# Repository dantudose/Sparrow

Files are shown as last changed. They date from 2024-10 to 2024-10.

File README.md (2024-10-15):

# Sparrow

## Arduino-compatible IoT sensor node made from two boards: the Node and the Nest - used for programming and debugging.

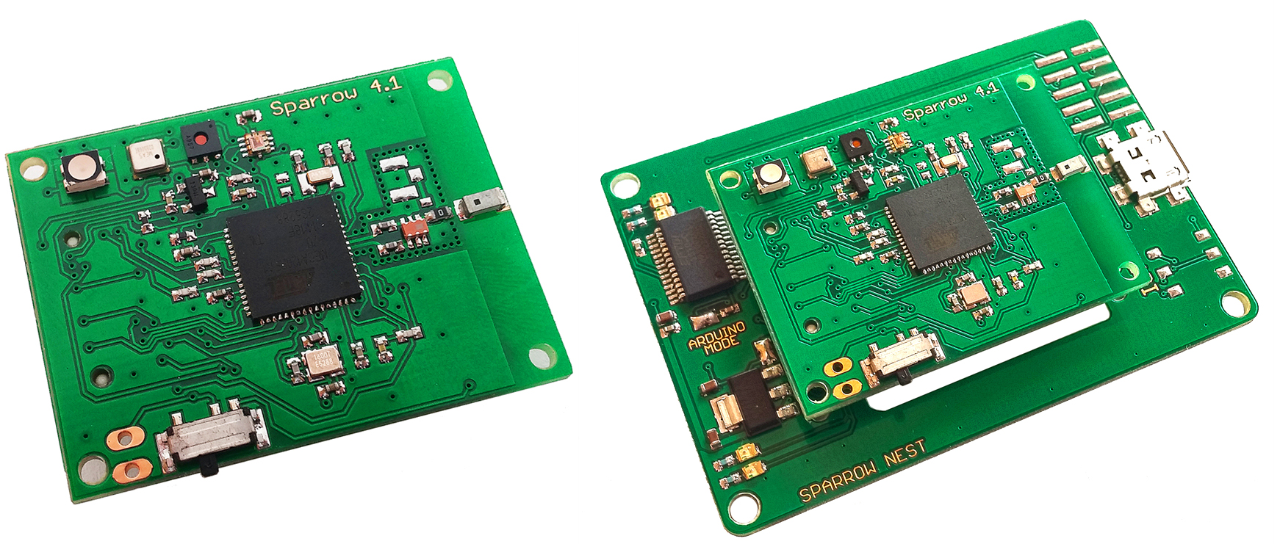
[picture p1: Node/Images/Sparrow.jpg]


Features include:

* Atmega128RFA1 8-bit AVR low-power microcontroller
* Integrated 2.4GHz radio transceiver
* Precision temperature & humidity sensor
* Barometer/altimeter
* Light sensor (visible, IR and UV spectrum, luxmeter and UV radiation index)
* High capacity CR2450 battery holder
* Fully-compatible with Arduino, with dedicated libraries for easy programming of the sensors and radio.

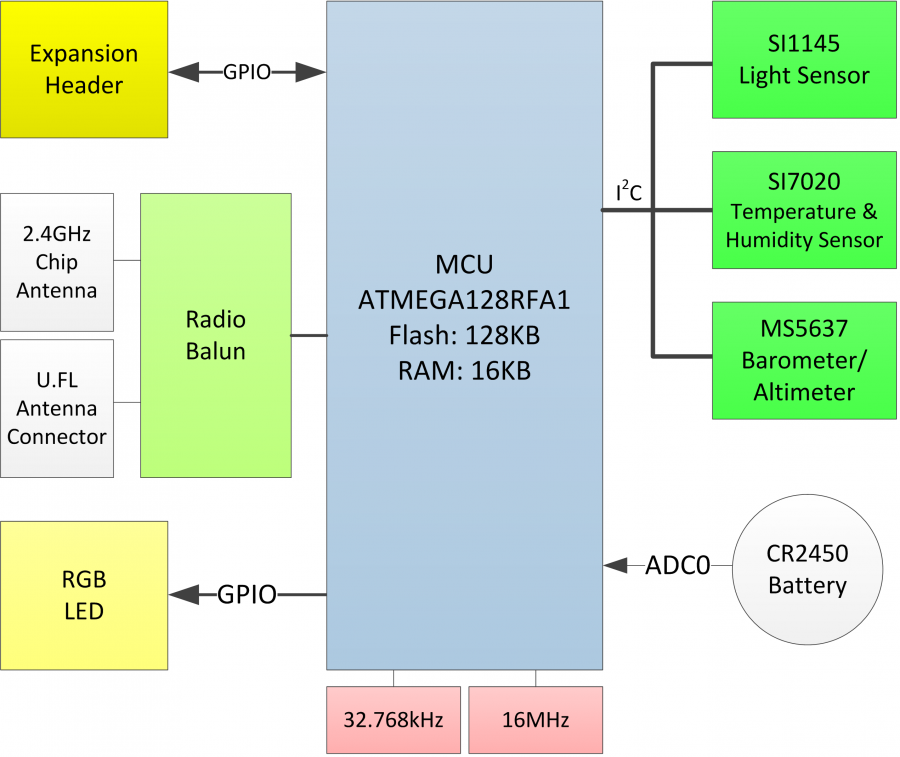
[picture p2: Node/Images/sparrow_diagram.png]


## Repository Contents

* **/Hardware** - Eagle design files (.brd, .sch)
* **/Images** - Board images
* **/bin** - Binaries (board bootloader)

## Programming

### Installing Arduino Libraries and Boad Configs

1. Open the Arduino IDE
2. Go to File → Preferences
3. In the Additional Boards Manager URLs textbox add the following link: http://clkdiv8.com/download/package_clkdiv8pre_index.json
4. Close the window by pressing OK
5. Go to Tools → Board → Boards Manager
6. Search “sparrow”
7. Hit Install
8. You're done!

### Tutorials

Most tutorials for using the on-board sensors or radio are available <a href="https://clkdiv8.com/wiki/doku.php/tutorials">here</a>.

### Bootloader
The board comes pre-loaded with a bootloader. Should you need to re-write it, connect an AVR-ISP or JTAG to the corresponding port and burn the <a href="https://github.com/dantudose/Sparrow/blob/main/Node/bin/">bootloader</a> .hex file with _atmega128rfa1_ as a target and the following fuse settings:

<table>
<thead>
  <tr>
    <th>Fuse</th>
    <th>Value</th>
  </tr>
</thead>
<tbody>
  <tr>
    <td>HIGH</td>
    <td>0xD0</td>
  </tr>
  <tr>
    <td>LOW</td>
    <td>0xF7</td>
  </tr>
  <tr>
    <td>EXT</td>
    <td>0XFE</td>
  </tr>
</tbody>
</table>

## Pinout and Sensor Addresses

<table><thead>
  <tr>
    <th></th>
    <th>GPIO Pin</th>
    <th>Arduino Pin</th>
    <th></th>
    <th>Sensor</th>
    <th>I2C Address</th>
  </tr></thead>
<tbody>
  <tr>
    <td>LED R</td>
    <td>PB4</td>
    <td>8</td>
    <td></td>
    <td>Si1145</td>
    <td>0x60</td>
  </tr>
  <tr>
    <td>LED G</td>
    <td>PB5</td>
    <td>11</td>
    <td></td>
    <td>Si7020</td>
    <td>0x40</td>
  </tr>
  <tr>
    <td>LED B</td>
    <td>PB6</td>
    <td>10</td>
    <td></td>
    <td>MS5637</td>
    <td>0x76</td>
  </tr>
  <tr>
    <td>Sensor <br>Enable <br> (Active LOW)</td>
    <td>PE7</td>
    <td>19</td>
    <td></td>
    <td></td>
    <td></td>
  </tr>
  <tr>
    <td>Battery<br>Level</td>
    <td>PF0</td>
    <td>A0</td>
    <td></td>
    <td></td>
    <td></td>
  </tr>
</tbody>
</table>

## License Information

This product is _**open source**_! 

Please review the LICENSE file for license information.

Distributed as-is; no warranty is given.

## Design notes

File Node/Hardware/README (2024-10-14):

Eagle (Fusion360) files and schematic in pdf format.

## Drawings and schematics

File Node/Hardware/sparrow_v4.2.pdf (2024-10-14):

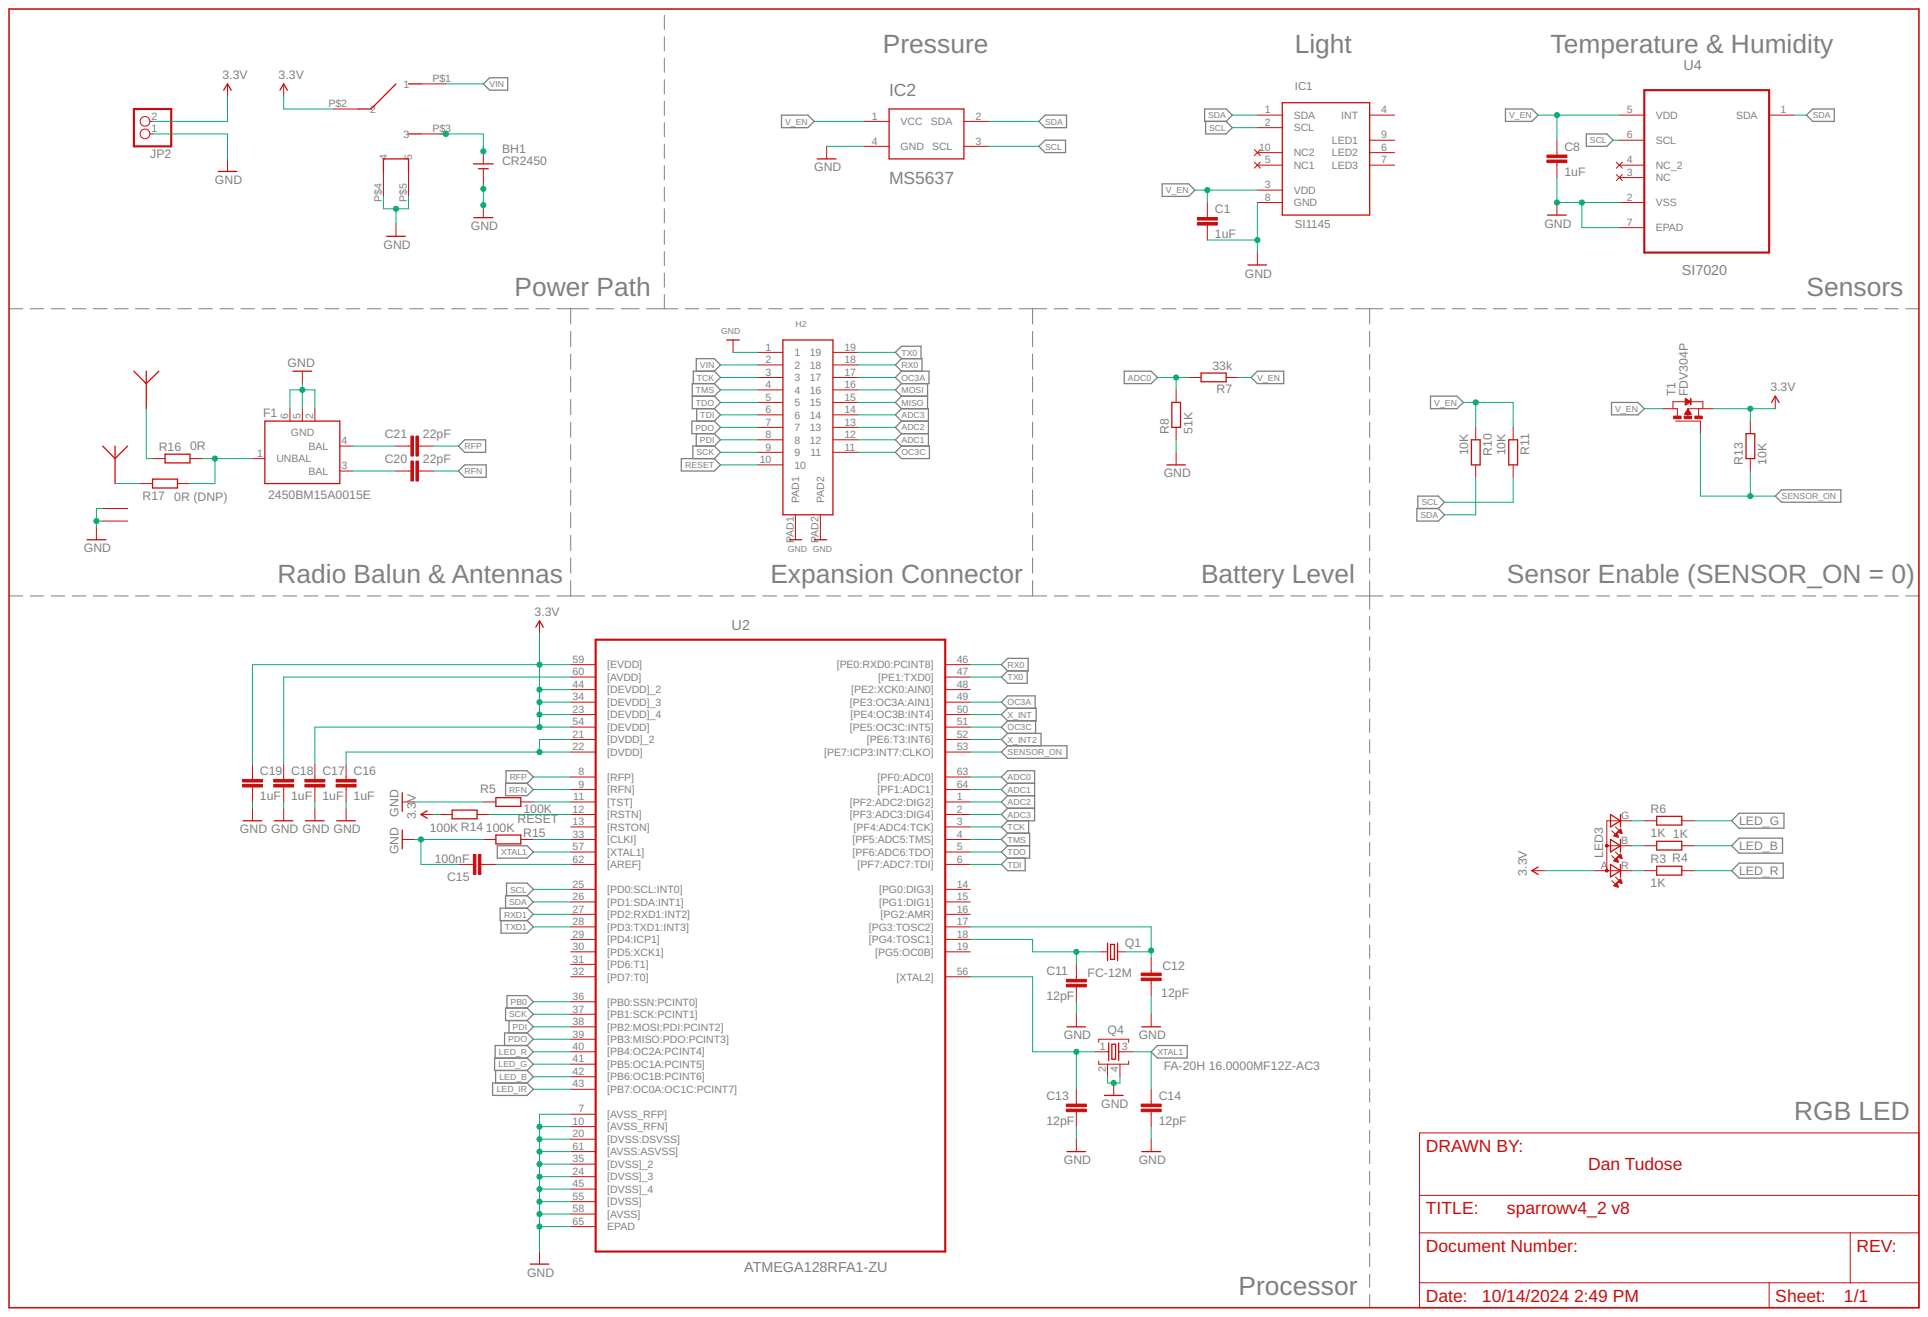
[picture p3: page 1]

Date: Sheet: | REV: TITLE: Document Number:

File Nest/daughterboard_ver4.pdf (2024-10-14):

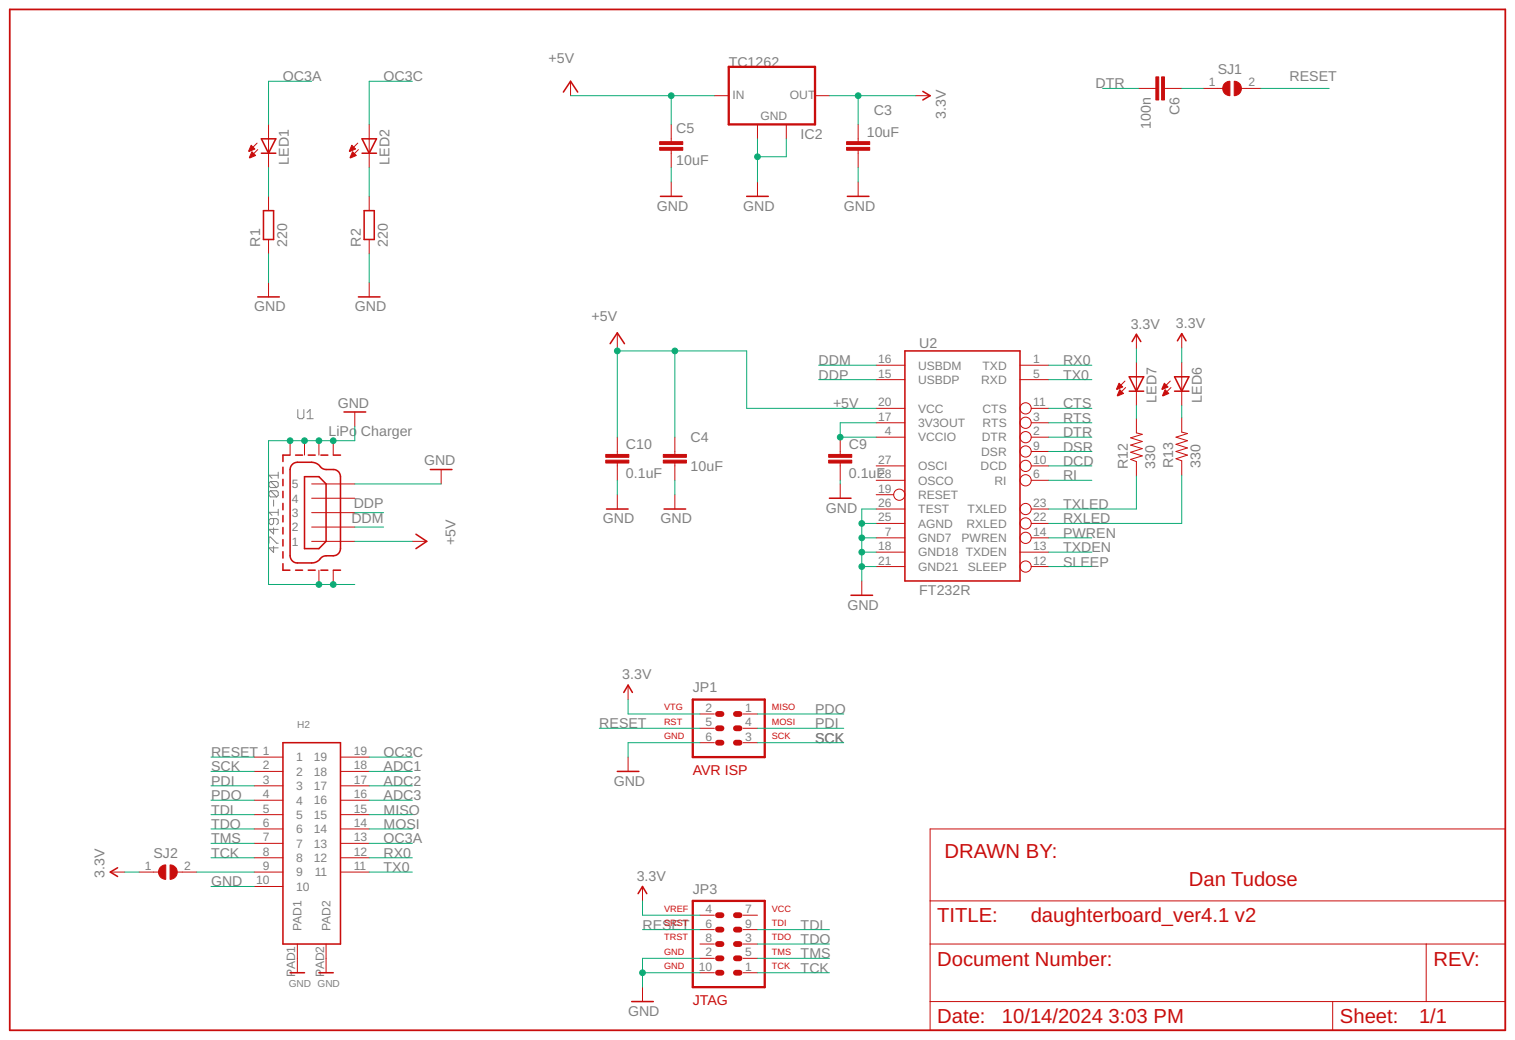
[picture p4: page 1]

Document Number: | REV:

Date: | Sheet:

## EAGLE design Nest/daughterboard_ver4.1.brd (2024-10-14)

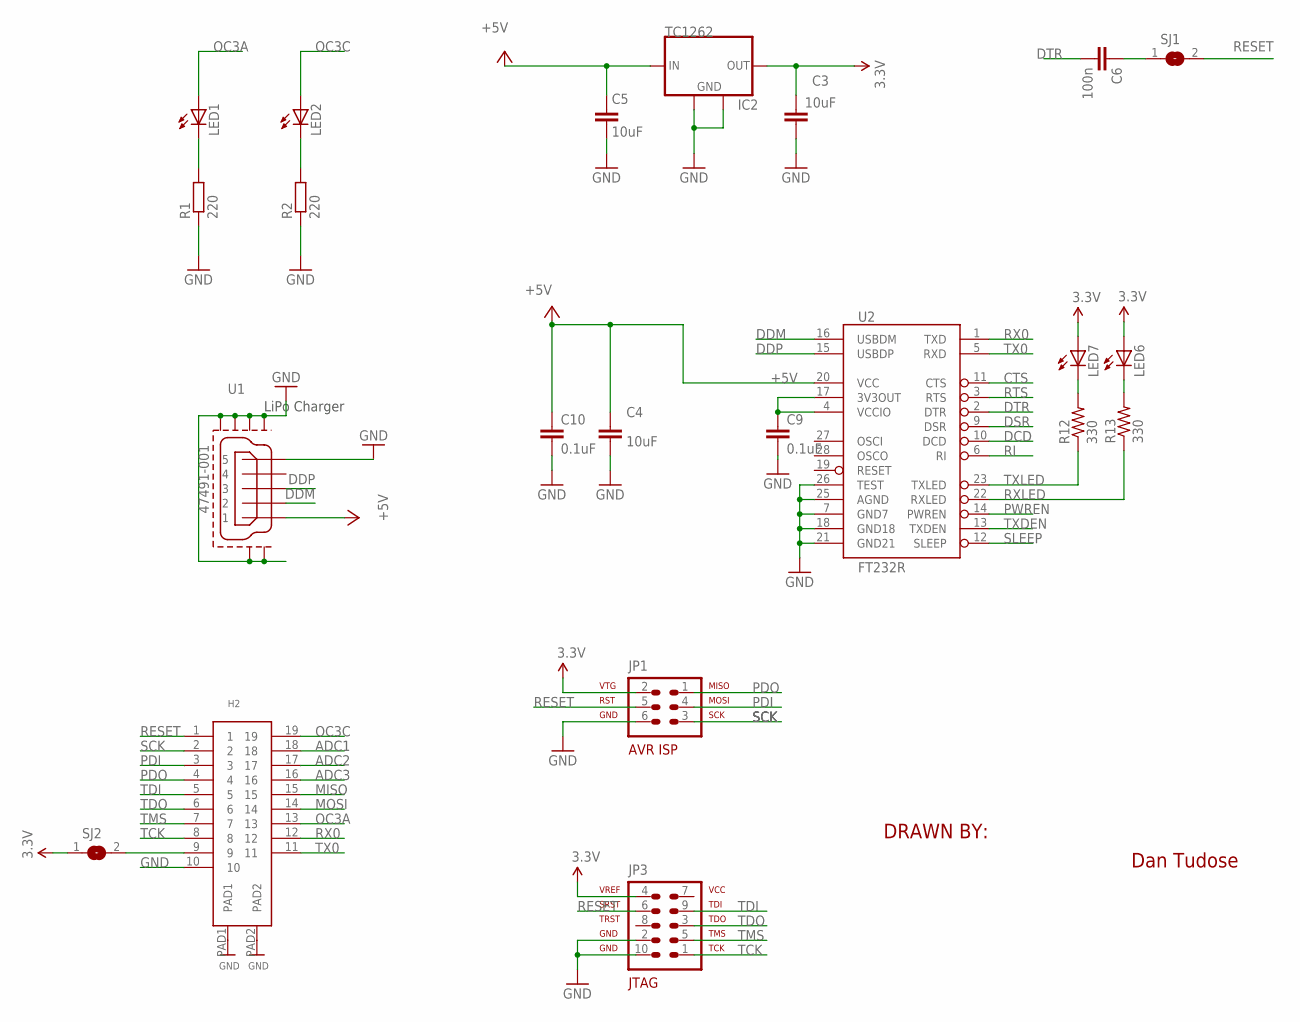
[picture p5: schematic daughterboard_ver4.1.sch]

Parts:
C3, C4, C5: 10uF; C0402
C6: 100n; C0402
C9, C10: 0.1uF; 0402-CAP
H2: DF9-19P-1V(32)
IC2: TC1262; SOT223
JP1: AVR-ISP-6SMD; 2X3SMD
JP3: AVR-JTAG-10
LED1, LED2: LEDCHIPLED_0603; CHIPLED_0603
LED6, LED7: LEDCHIP-LED0603; CHIP-LED0603
R1, R2: 220; R0402
R12, R13: 330; 0402-RES
SJ1, SJ2: SJ
U1: 47491-001; 47491-0001
U2: FT232R; SSOP28DB

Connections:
3.3V: C3.1, IC2.3 (OUT), JP1.2, JP3.4, LED6.A, LED7.A, SJ2.1
+5V: C4.1, C5.1, C10.1, IC2.1 (IN), U1.1, U2.20 (VCC)
ADC1: H2.18
ADC2: H2.17
ADC3: H2.16
CTS: U2.11 (CTS)
DCD: U2.10 (DCD)
DDM: U1.2, U2.16 (USBDM)
DDP: U1.3, U2.15 (USBDP)
DSR: U2.9 (DSR)
DTR: C6.2, U2.2 (DTR)
GND: C3.2, C4.2, C5.2, C9.2, C10.2, H2.10, H2.PAD1, H2.PAD2, IC2.2 (GND), IC2.4 (GND), JP1.6, JP3.2, JP3.10, R1.1, R2.1, U1.5, U1.GND1, U1.GND2, U1.GND3, U1.GND4, U1.GND5, U1.GND6, U2.7 (GND7), U2.18 (GND18), U2.21 (GND21), U2.25 (AGND), U2.26 (TEST)
MISO: H2.15
MOSI: H2.14
unnamed: LED7.C, R12.2
unnamed: LED6.C, R13.2
unnamed: H2.9, SJ2.2
unnamed: LED1.C, R1.2
unnamed: LED2.C, R2.2
unnamed: C9.1, U2.4 (VCCIO), U2.17 (3V3OUT)
unnamed: C6.1, SJ1.1
OC3A: H2.13, LED1.A
OC3C: H2.19, LED2.A
PDI: H2.3, JP1.4
PDO: H2.4, JP1.1
PWREN: U2.14 (PWREN)
RESET: H2.1, JP1.5, JP3.6, SJ1.2
RI: U2.6 (RI)
RTS: U2.3 (RTS)
RX0: H2.12, U2.1 (TXD)
RXLED: R13.1, U2.22 (RXLED)
SCK: H2.2, JP1.3
SLEEP: U2.12 (SLEEP)
TCK: H2.8, JP3.1
TDI: H2.5, JP3.9
TDO: H2.6, JP3.3
TMS: H2.7, JP3.5
TX0: H2.11, U2.5 (RXD)
TXDEN: U2.13 (TXDEN)
TXLED: R12.1, U2.23 (TXLED)

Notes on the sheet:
LiPo Charger
DRAWN BY:
Dan Tudose

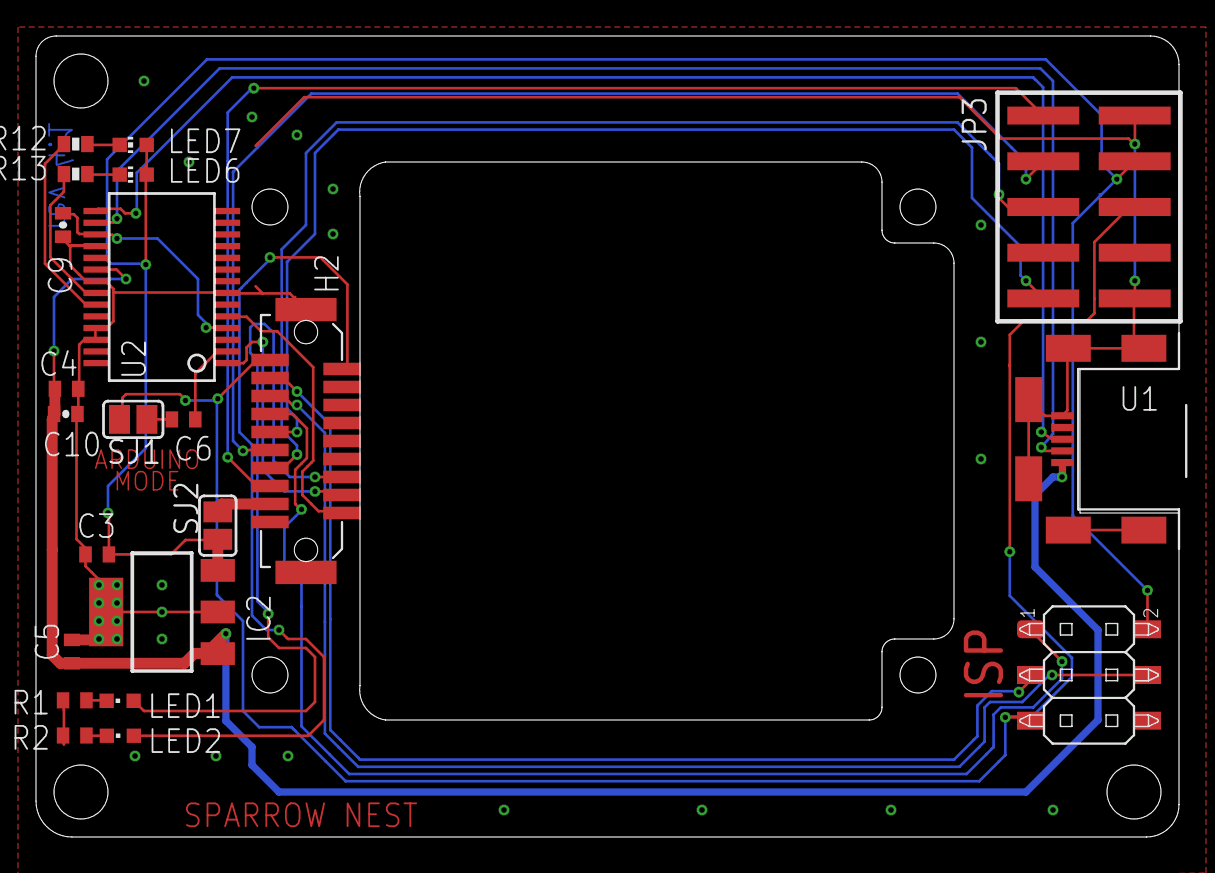
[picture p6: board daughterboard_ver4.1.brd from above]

Board: 2 copper layers, 63.5 x 44.5 mm, 22 parts (0 on the bottom side), 27 nets.

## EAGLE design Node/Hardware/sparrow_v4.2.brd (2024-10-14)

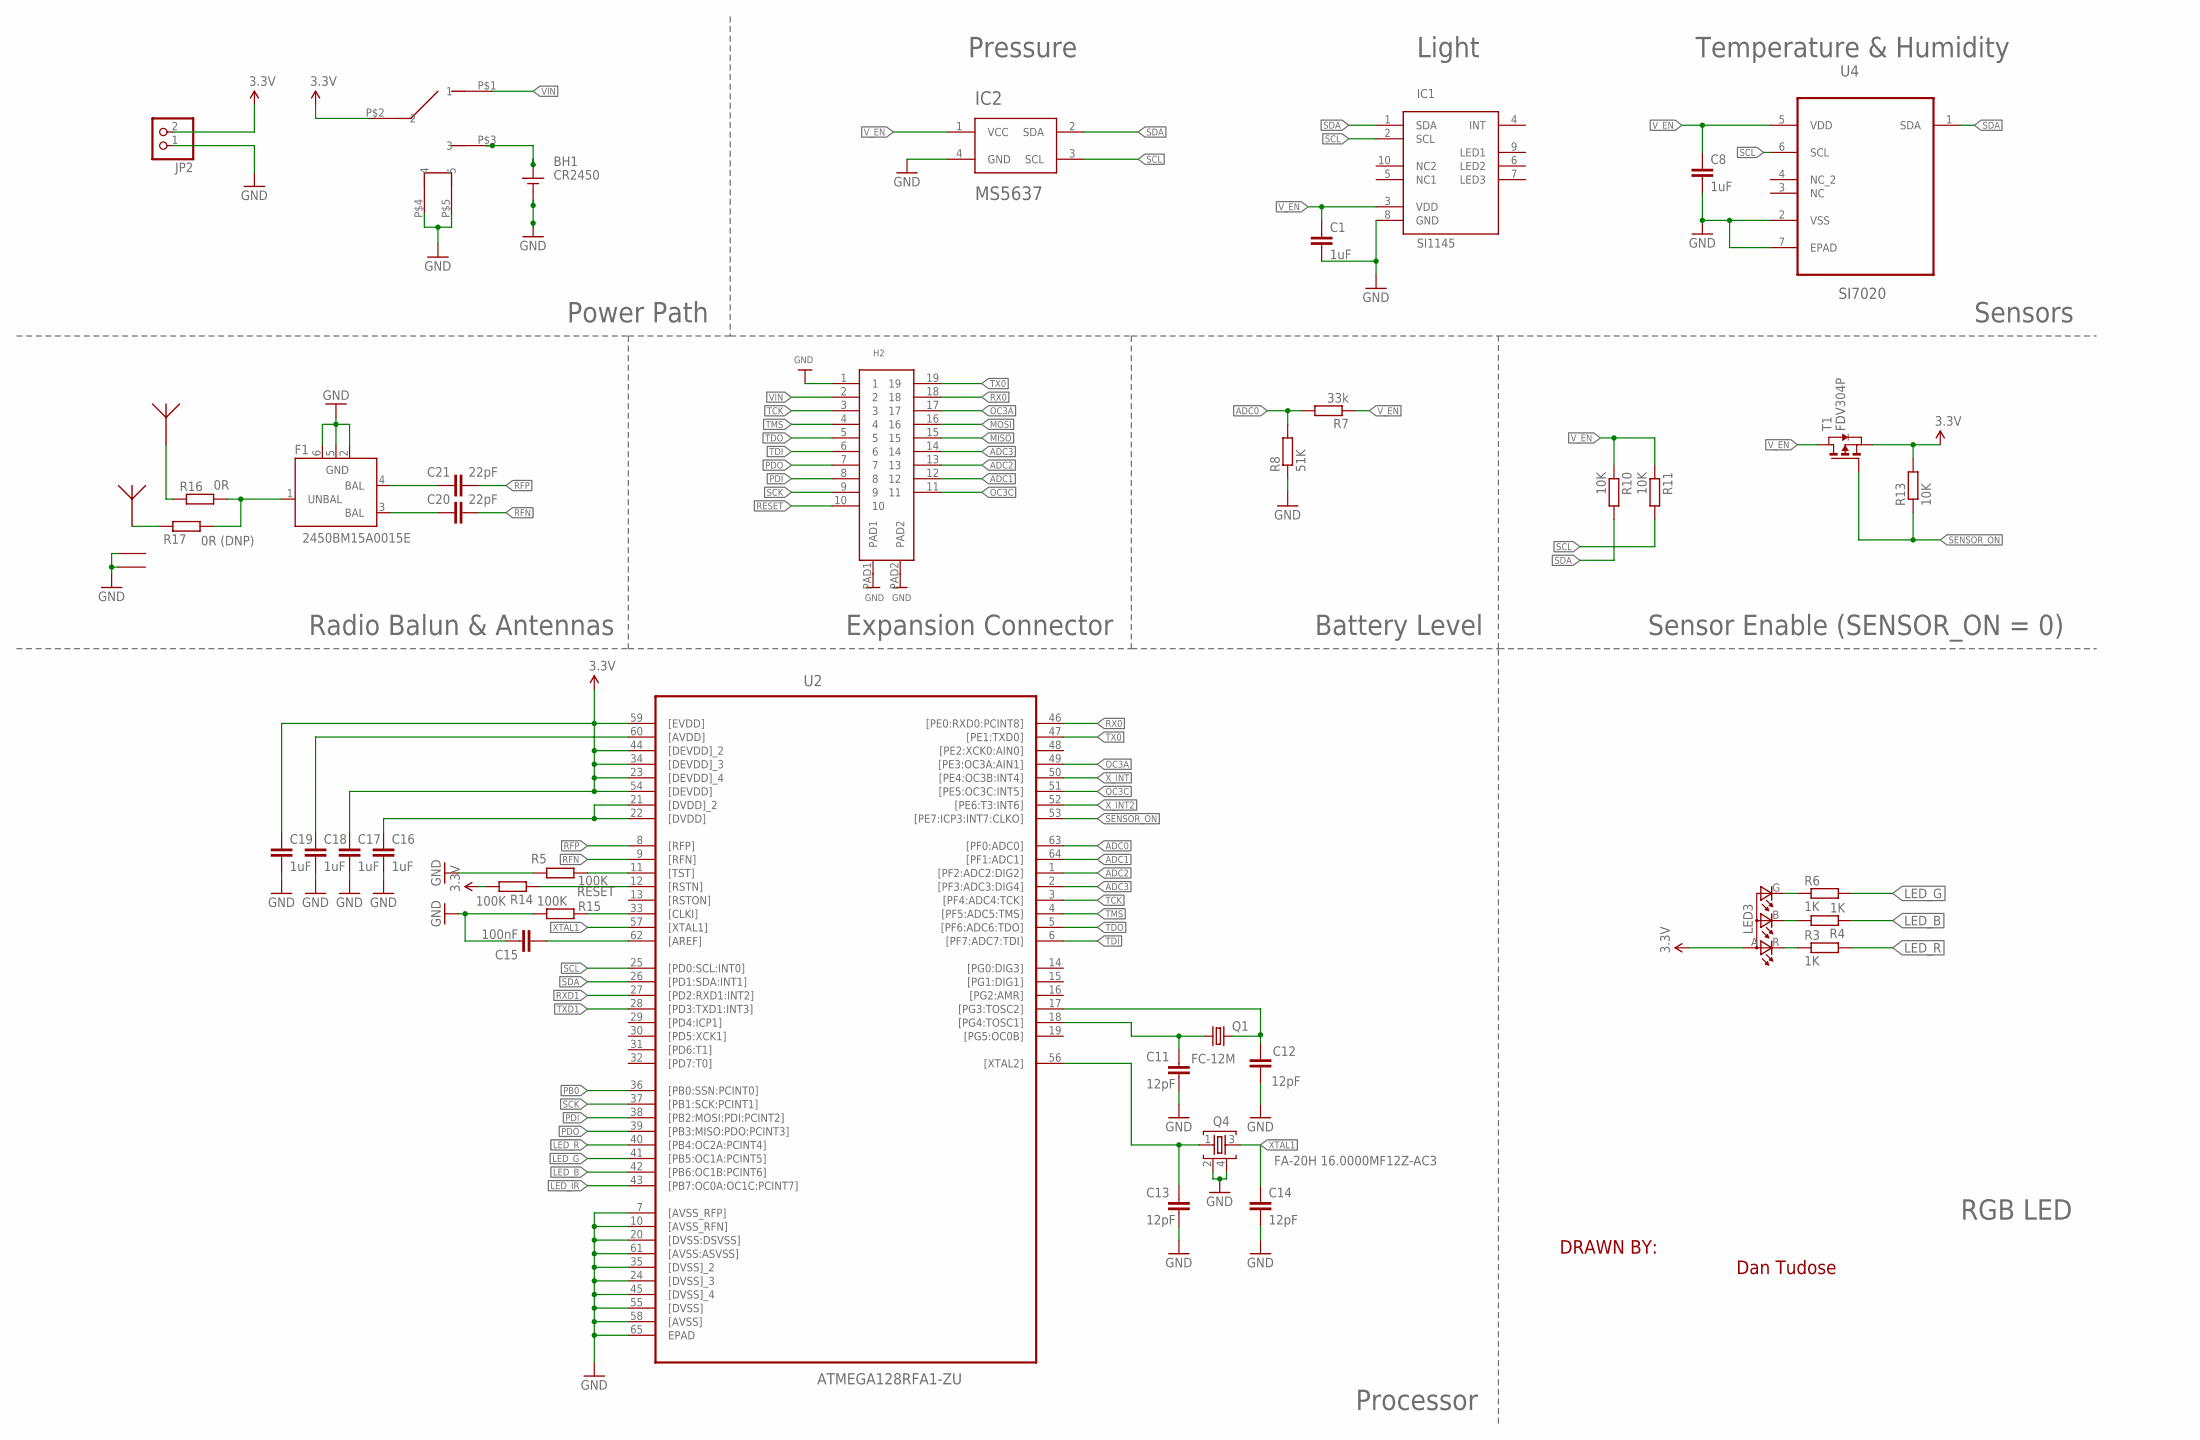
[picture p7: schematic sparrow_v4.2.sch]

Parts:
C1, C8, C16, C17, C18, C19: 1uF; C0402
C11, C12, C13, C14: 12pF; C0402
C15: 100nF; C0402
C20, C21: 22pF; C0402
F1: 2450BM15A0015E; 2450BM15A0002
H2: DF9-19P-1V(32)
IC1: SI1145; QFN10
IC2: MS5637
JP2: PINHD-1X2; 1X02
LED3: LED_RGB_CREE_PLCC4; P-LCC-4-4
Q1: FC-12M
Q4: FA-20H 16.0000MF12Z-AC3; FA-20H
R3, R4, R6: 1K; R0402
R5, R14, R15: 100K; R0402
R7: 33k; R0402
R8: 51K; R0402
R10, R11, R13: 10K; R0402
R16: 0R; R0402
R17: 0R (DNP); R0402
T1: FDV304P; SOT-23
U1: SMTU2450N-LF; BATPACK
U2: ATMEGA128RFA1-ZU; QFN50P900X900X90-64N
U4: SI7020; DFN300X300X110-7N
U8: ANTENNA; ANTPACK
U10: UFL-R-SMT; U.FLPACK
U$1: SWITCH; PCM12

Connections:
3.3V: C17.1, C19.1, JP2.2, LED3.A (A2), R13.2, R14.2, T1.2 (S), U2.23 ([DEVDD]_4), U2.34 ([DEVDD]_3), U2.44 ([DEVDD]_2), U2.54 ([DEVDD]), U2.59 ([EVDD]), U$1.P$2 (2)
ADC0: R7.2, R8.2, U2.63 ([PF0:ADC0])
ADC1: H2.12, U2.64 ([PF1:ADC1])
ADC2: H2.13, U2.1 ([PF2:ADC2:DIG2])
ADC3: H2.14, U2.2 ([PF3:ADC3:DIG4])
GND: C1.2, C8.2, C11.2, C12.2, C13.2, C14.2, C15.1, C16.2, C17.2, C18.2, C19.2, F1.2 (GND), F1.5 (GND), F1.6 (GND), H2.1, H2.PAD1, H2.PAD2, IC1.8 (GND), IC2.4 (GND), JP2.1, Q4.2, Q4.4, R5.2, R8.1, R15.2, U1.P$2, U2.7 ([AVSS_RFP]), U2.10 ([AVSS_RFN]), U2.20 ([DVSS:DSVSS]), U2.24 ([DVSS]_3), U2.35 ([DVSS]_2), U2.45 ([DVSS]_4), U2.55 ([DVSS]), U2.58 ([AVSS]), U2.61 ([AVSS:ASVSS]), U2.65 (EPAD), U4.2 (VSS), U4.7 (EPAD), U10.GND1, U10.GND2, U$1.P$4 (4), U$1.P$5 (5)
LED_B: R4.1, U2.42 ([PB6:OC1B:PCINT6])
LED_G: R6.2, U2.41 ([PB5:OC1A:PCINT5])
LED_IR: U2.43 ([PB7:OC0A:OC1C:PCINT7])
LED_R: R3.2, U2.40 ([PB4:OC2A:PCINT4])
MISO: H2.15
MOSI: H2.16
unnamed: U1.P$1, U$1.P$3 (3)
unnamed: C16.1, U2.21 ([DVDD]_2), U2.22 ([DVDD])
unnamed: LED3.R (CRED), R3.1
unnamed: C12.1, Q1.2, U2.17 ([PG3:TOSC2])
unnamed: C11.1, Q1.1, U2.18 ([PG4:TOSC1])
unnamed: LED3.B (CBLUE), R4.2
unnamed: LED3.G (CGREEN), R6.1
unnamed: C18.1, U2.60 ([AVDD])
unnamed: R5.1, U2.11 ([TST])
unnamed: C13.1, Q4.1, U2.56 ([XTAL2])
unnamed: R15.1, U2.33 ([CLKI])
unnamed: C15.2, U2.62 ([AREF])
unnamed: C20.1, F1.3 (BAL)
unnamed: C21.1, F1.4 (BAL)
unnamed: F1.1 (UNBAL), R16.2, R17.1
unnamed: R16.1, U8.P$1
unnamed: R17.2, U10.P$1
OC3A: H2.17, U2.49 ([PE3:OC3A:AIN1])
OC3C: H2.11, U2.51 ([PE5:OC3C:INT5])
PB0: U2.36 ([PB0:SSN:PCINT0])
PDI: H2.8, U2.38 ([PB2:MOSI:PDI:PCINT2])
PDO: H2.7, U2.39 ([PB3:MISO:PDO:PCINT3])
RESET: H2.10, R14.1, U2.12 ([RSTN])
RFN: C20.2, U2.9 ([RFN])
RFP: C21.2, U2.8 ([RFP])
RX0: H2.18, U2.46 ([PE0:RXD0:PCINT8])
RXD1: U2.27 ([PD2:RXD1:INT2])
SCK: H2.9, U2.37 ([PB1:SCK:PCINT1])
SCL: IC1.2 (SCL), IC2.3 (SCL), R11.2, U2.25 ([PD0:SCL:INT0]), U4.6 (SCL)
SDA: IC1.1 (SDA), IC2.2 (SDA), R10.2, U2.26 ([PD1:SDA:INT1]), U4.1 (SDA)
SENSOR_ON: R13.1, T1.3 (G), U2.53 ([PE7:ICP3:INT7:CLKO])
TCK: H2.3, U2.3 ([PF4:ADC4:TCK])
TDI: H2.6, U2.6 ([PF7:ADC7:TDI])
TDO: H2.5, U2.5 ([PF6:ADC6:TDO])
TMS: H2.4, U2.4 ([PF5:ADC5:TMS])
TX0: H2.19, U2.47 ([PE1:TXD0])
TXD1: U2.28 ([PD3:TXD1:INT3])
VIN: H2.2, U$1.P$1 (1)
V_EN: C1.1, C8.1, IC1.3 (VDD), IC2.1 (VCC), R7.1, R10.1, R11.1, T1.1 (D), U4.5 (VDD)
XTAL1: C14.1, Q4.3, U2.57 ([XTAL1])
X_INT: U2.50 ([PE4:OC3B:INT4])
X_INT2: U2.52 ([PE6:T3:INT6])

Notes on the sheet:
DRAWN BY:
Dan Tudose
CR2450
BH1
Sensor Enable (SENSOR_ON = 0)
Sensors
Battery Level
RGB LED
Expansion Connector
Radio Balun & Antennas
Power Path
Processor
Pressure
Light
Temperature & Humidity

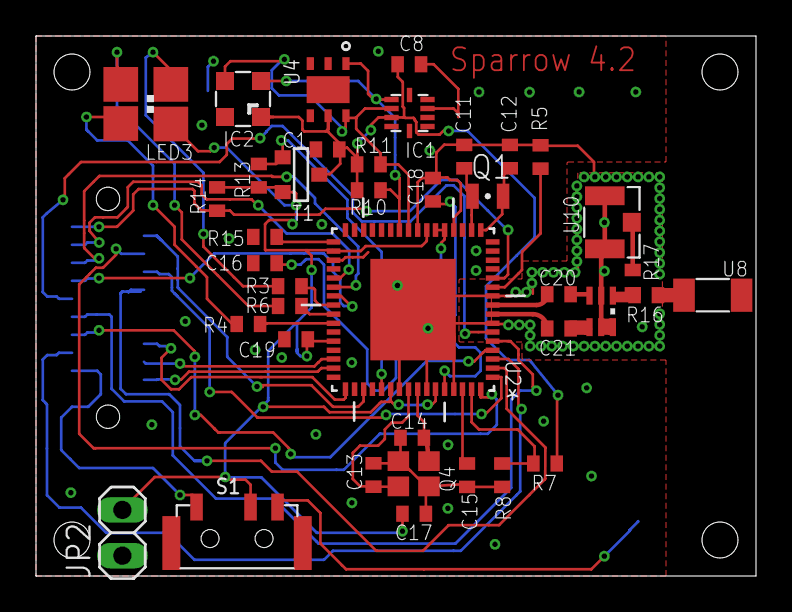
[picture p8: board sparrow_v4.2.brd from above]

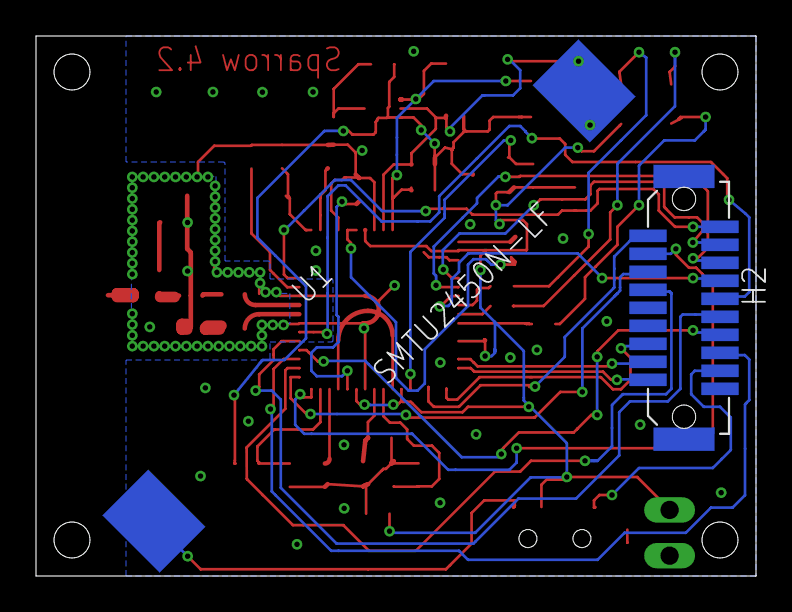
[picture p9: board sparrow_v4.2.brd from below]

Board: 2 copper layers, 40.0 x 30.0 mm, 41 parts (2 on the bottom side), 46 nets.
